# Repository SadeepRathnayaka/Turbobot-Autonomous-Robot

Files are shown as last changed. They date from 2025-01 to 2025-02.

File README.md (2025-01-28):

# Turbobot-Autonomous-Robot

This repository showcases a four-wheel differential drive robot designed and built from scratch. It includes the 3D model design, ROS2 framework integration, localization using EKF, firmware implementation, and hardware bringup. Below are the key aspects of the project:

https://github.com/user-attachments/assets/a37dd53c-2390-4a10-aca8-deebb67d79c1

---

## Table of Contents

1. [3D Model Design](#3d-model-design)
2. [ROS2 Framework Configuration](#ros2-framework-configuration)
3. [ROS2 Localization with EKF](#ros2-localization-with-ekf)
4. [Turbobot Firmware Package](#turbobot-firmware-package)
5. [Turbobot Bringup Package](#turbobot-bringup-package)
6. [TODO](#todo)
7. [Contributing](#contributing)

---

## 3D Model Design

The robot chassis and components were designed in SolidWorks with a focus on robustness and simplicity. Key design features include:

- **Chassis**: Compact and durable, optimized for differential drive control.
- **Motors and Wheels**: Equipped with four 12V DC motors with encoders for precise movement and control.
- **Sensors**: Design accommodates IMU and encoders for accurate localization.

https://github.com/user-attachments/assets/6d96dd51-13d0-4719-9e16-4e17023ca4d6

---

## ROS2 Framework Configuration

The robot is integrated with the ROS2 framework to enable advanced robotic functionalities. The configuration is divided into:

### 1. Turbobot Description Package
- **URDF File**: Created a URDF file from the Solidworks to accurately describe its physical structure.
- **RViz Visualization**: Used RViz2 for real-time visualization of the robot model and its movements.

### 2. Turbobot Controller Package
- **Differential Drive Controller**: Configured the ROS2 control package to manage differential drive mechanics and handle wheel commands.
- **Joint State Publishing**: Ensures real-time feedback of wheel states for visualization and control.

https://github.com/user-attachments/assets/6af6fd65-e95c-474f-9c42-16ca92db2a46

https://github.com/user-attachments/assets/eaf015e2-bc32-4cbf-b950-43cc5cfae7bc

---

## ROS2 Localization with EKF

Localization is implemented using the Extended Kalman Filter (EKF) through the `robot_localization` package. This setup fuses sensor data to provide robust state estimation:

- **Sensor Fusion**: Combines data from wheel encoders and an IMU sensor.
- **EKF Implementation**: Filters noisy sensor data for accurate pose and velocity estimation.

---

## Turbobot Firmware Package

The firmware developed for the robot provides seamless communication between hardware and software:

- **Serial Communication**: Reads commands from ROS2 control via serial interface.
- **Encoder Feedback**: Sends wheel encoder data back to ROS2 control for real-time updates.

https://github.com/user-attachments/assets/950cfb9a-0e33-45bd-b91e-5be3077a2346

https://github.com/user-attachments/assets/f371da3b-ce15-4cfa-9a51-53758e793328

---

## Turbobot Bringup Package

The bringup package initializes and visualizes the robot’s hardware or simulation:

- **Hardware Setup**: Launch file to start the physical robot.
- **Simulated Setup**: RViz2 integration to visualize and test the robot in a simulated environment.

https://github.com/user-attachments/assets/525a8be4-f4b9-4b29-8b2c-a98935a81687

---

## TODO

Future improvements and features:

1. Add a LiDAR sensor for environment scanning.
2. Integrate `nav2` and `slam_toolbox` for autonomous navigation and SLAM.

---

## Contributing

Contributions are welcome! Feel free to submit issues or pull requests for improvements and additional features.

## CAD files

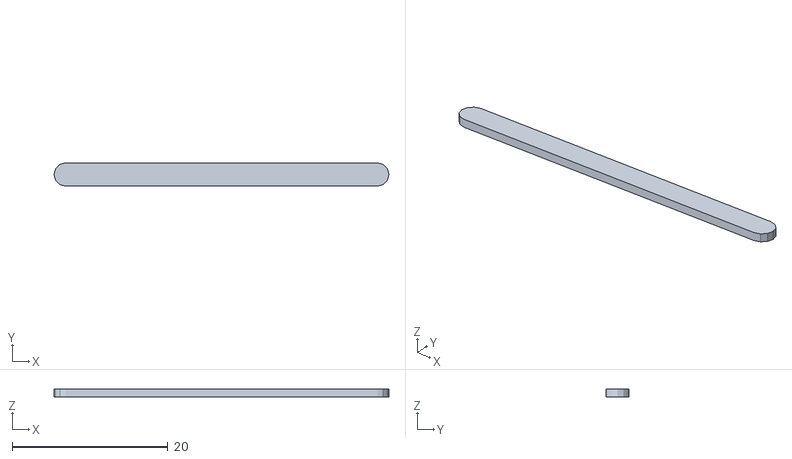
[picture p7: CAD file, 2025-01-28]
CAD Models/Part9_White.STL
43.0 x 3.00 x 1.00

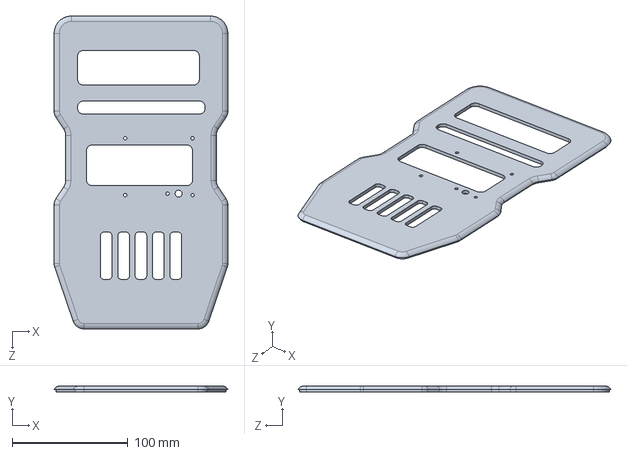
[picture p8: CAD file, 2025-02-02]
CAD Models/Solidworks Parts/Part2.SLDPRT
150.0 x 5.00 x 270.0 mm

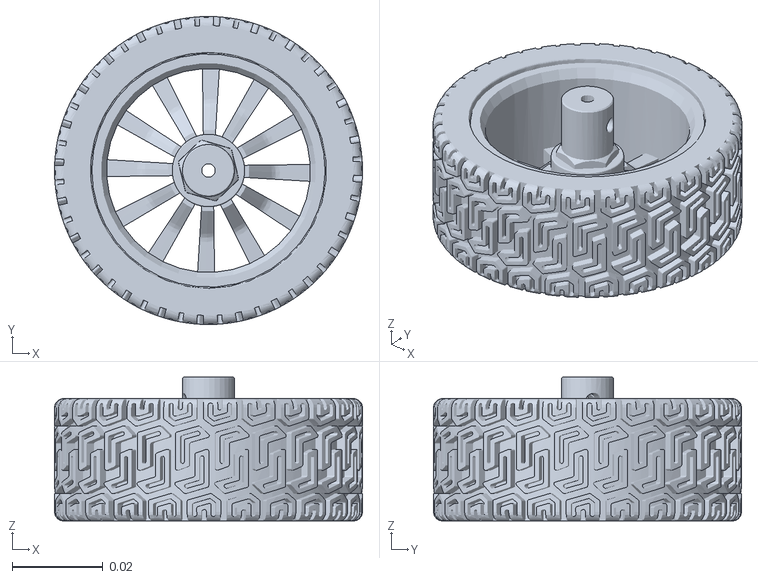
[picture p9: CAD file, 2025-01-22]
turbobot_description/meshes/right_front_wheel_link.STL
0.068 x 0.068 x 0.0318

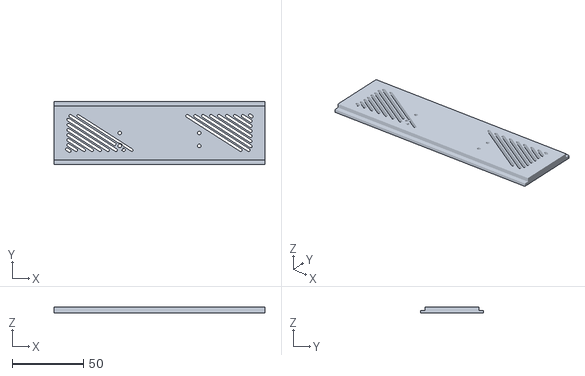
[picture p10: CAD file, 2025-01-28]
CAD Models/Part12.STL
148.0 x 44.0 x 4.50

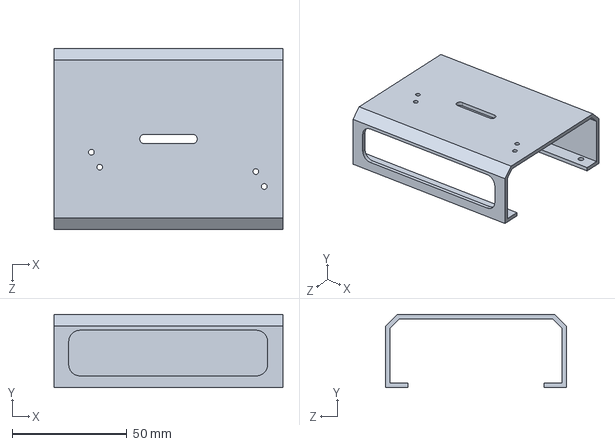
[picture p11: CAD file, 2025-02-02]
CAD Models/Solidworks Parts/Part3.SLDPRT
100.0 x 32.0 x 79.2 mm

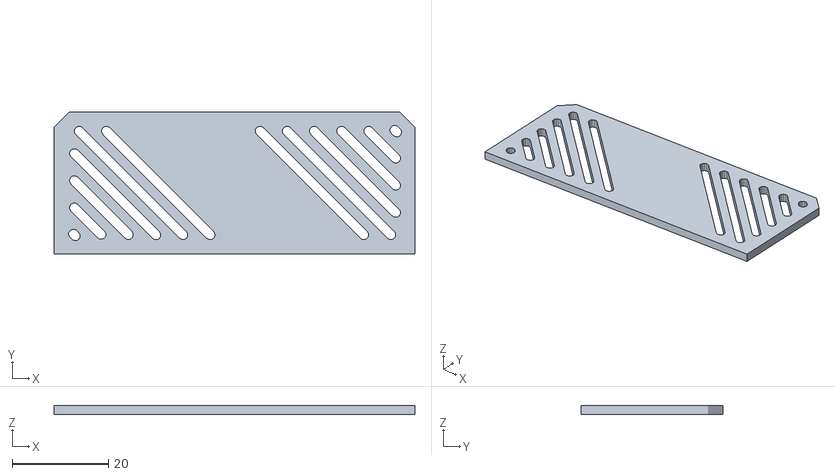
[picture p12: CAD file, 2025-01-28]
CAD Models/Part7.STL
75.2 x 29.6 x 1.90

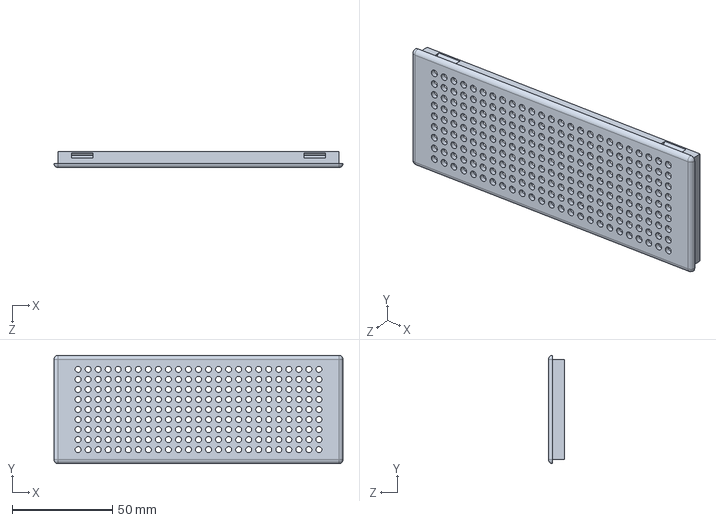
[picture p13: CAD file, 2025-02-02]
CAD Models/Solidworks Parts/Battery_Enclosure_Cover.SLDPRT
144.0 x 54.0 x 8.00 mm

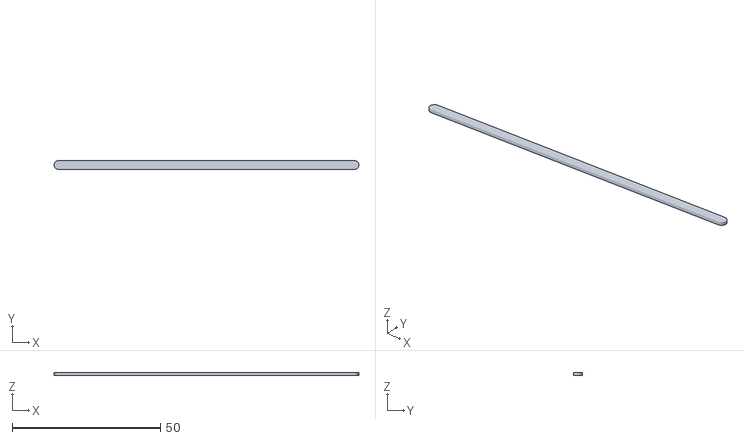
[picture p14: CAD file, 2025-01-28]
CAD Models/Part11_White.STL
103.0 x 3.00 x 1.00

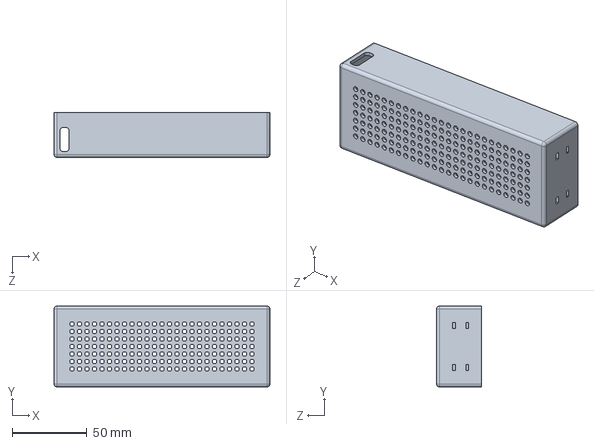
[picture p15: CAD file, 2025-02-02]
CAD Models/Solidworks Parts/Battery_Enclosure_Base.SLDPRT
144.0 x 54.0 x 30.0 mm

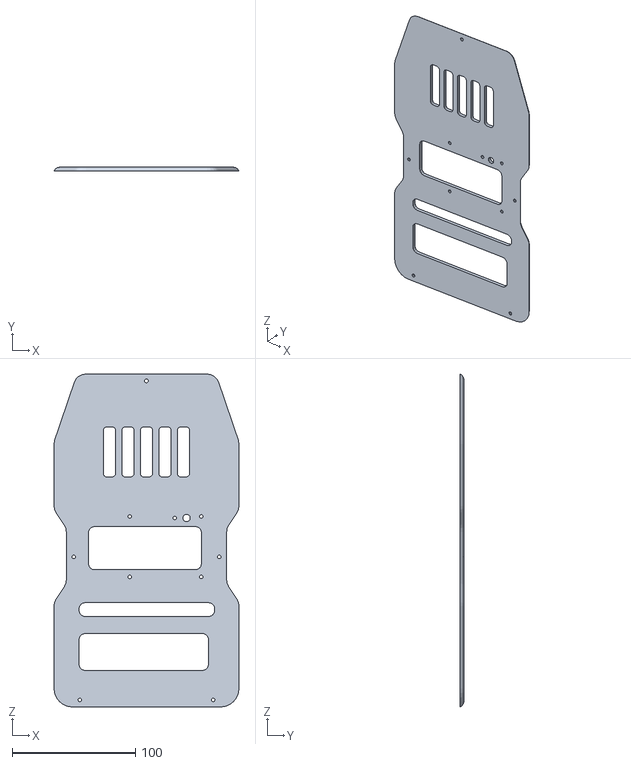
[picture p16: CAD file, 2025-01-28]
CAD Models/Part2_White.STL
150.0 x 3.00 x 270.0

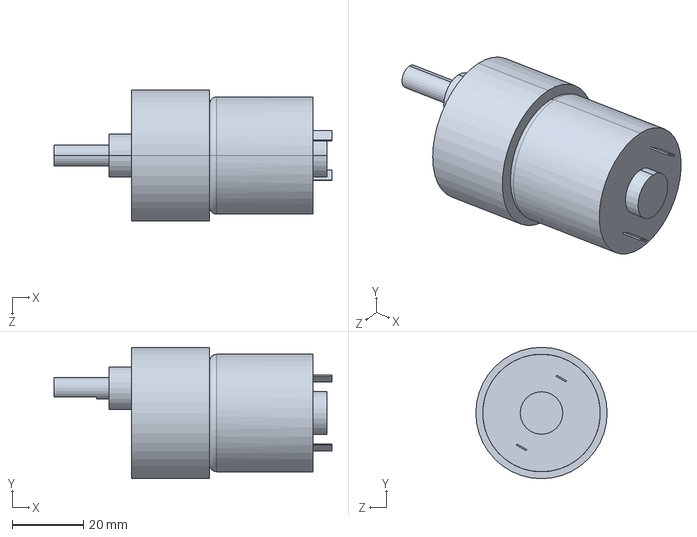
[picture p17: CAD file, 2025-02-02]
CAD Models/Solidworks Parts/DC Gearbox Motor SGD37.step.SLDPRT
78.3 x 37.0 x 37.0 mm

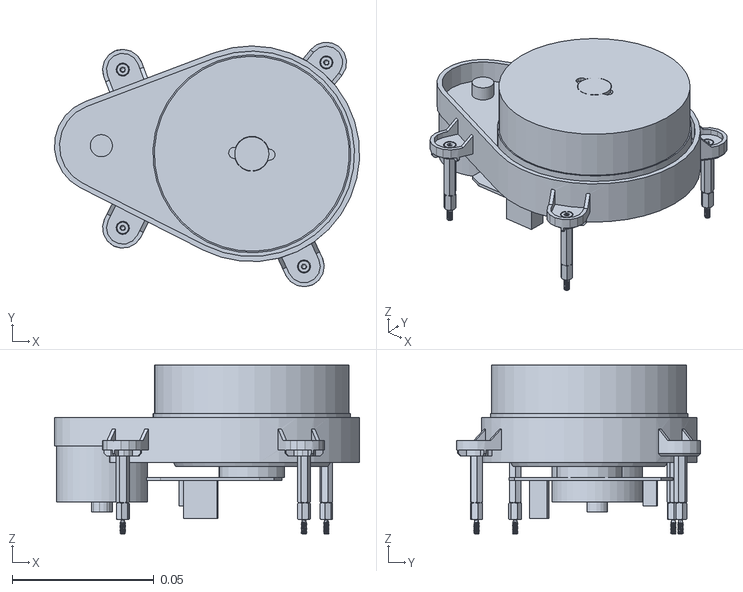
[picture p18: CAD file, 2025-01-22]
turbobot_description/meshes/lidar_link.STL
0.107 x 0.0861 x 0.0595

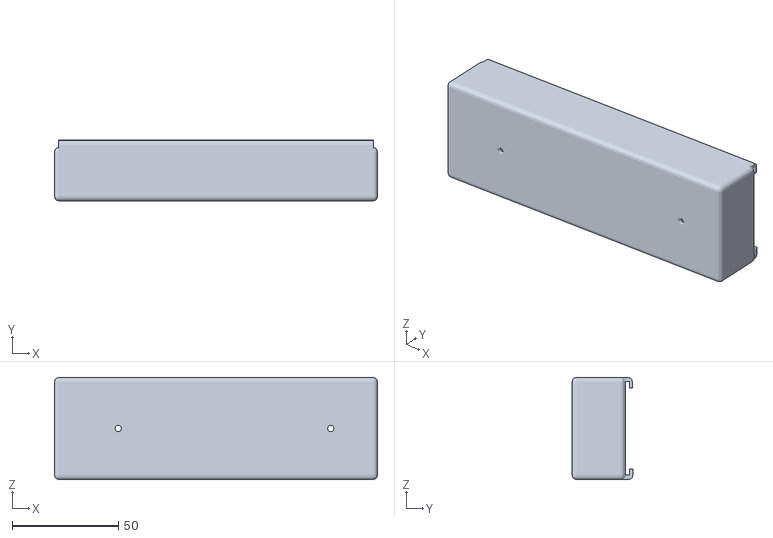
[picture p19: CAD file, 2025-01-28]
CAD Models/Part5.STL
152.0 x 28.5 x 48.0

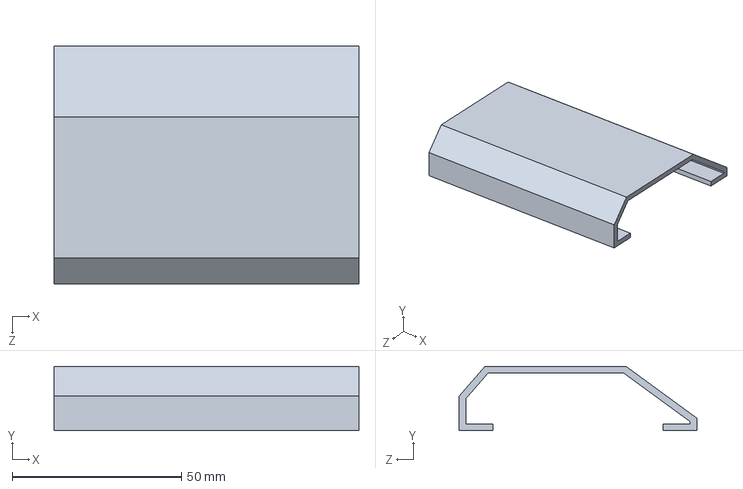
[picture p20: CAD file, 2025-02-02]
CAD Models/Solidworks Parts/Part4.SLDPRT
90.0 x 19.0 x 70.2 mm

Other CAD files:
turbobot_description/meshes/left_front_wheel_link.STL
turbobot_description/meshes/left_back_wheel_link.STL
turbobot_description/meshes/right_back_wheel_link.STL
turbobot_description/meshes/base_link.STL
CAD Models/Part1.STL
CAD Models/Part10_White.STL
CAD Models/Part3.STL
CAD Models/Part4.STL
CAD Models/Part8.STL
CAD Models/Solidworks Parts/MPU6050.SLDPRT
CAD Models/Solidworks Parts/Part1.SLDPRT
CAD Models/Solidworks Parts/Xiaomi Roborock Mi LDS02RR 1st gen LiDAR.SLDPRT
turbobot_description/meshes/IMU_link.STL

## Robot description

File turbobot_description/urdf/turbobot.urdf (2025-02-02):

<?xml version="1.0" encoding="utf-8"?>

<robot name="turbobot" xmlns:xacro="http://ros.org/wiki/xacro">

  <xacro:arg name="is_sim" default="true"/>

  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
  <xacro:include filename="$(find turbobot_description)/urdf/turbobot_gazebo.xacro" />
 
  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
  <xacro:include filename="$(find turbobot_description)/urdf/turbobot_ros2_control.xacro" />


  <link name="base_link">
    <inertial>
      <origin xyz="-0.0106412381739105 0.000371303474620305 0.0284727132515347" rpy="0 0 0" />
      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
        <mass value="0.283253612923317" />
      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
    </inertial>
    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
  </link>

  <link name="left_front_wheel_link">
    <inertial>
      <origin xyz="0.000111982737798819 8.35469957105595E-11 0.00621009180993898" rpy="0 0 0" />
      <mass value="0.0351743502617622" />
      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
    </inertial>
    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
  </link>

  <joint name="left_front_wheel_joint" type="continuous">
    <origin xyz="0.054789 0.094013 0.014388" rpy="-1.5708 -1.5708 0" />
    <parent link="base_link" />
    <child link="left_front_wheel_link" />
    <axis xyz="0 0 1" />
    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
  </joint>

  <link name="left_back_wheel_link">
    <inertial>
      <origin xyz="0.000111984234280757 7.10155073635477E-10 0.00621009181067783" rpy="0 0 0" />
      <mass value="0.0351743510827554" />
      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
    </inertial>
    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
  </link>

  <joint name="left_back_wheel_joint" type="continuous">
    <origin xyz="-0.082396 0.094013 0.014388" rpy="-1.5708 -1.5708 0" />
    <parent link="base_link" />
    <child link="left_back_wheel_link" />
    <axis xyz="0 0 1" />
    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
  </joint>

  <link name="right_front_wheel_link">
    <inertial>
      <origin xyz="-2.96807439736924E-11 -9.20698883413382E-05 -0.00621009190374883" rpy="0 0 0" />
      <mass value="0.0351743518709708" />
      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
    </inertial>
    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
  </link>

  <joint name="right_front_wheel_joint" type="continuous">
    <origin xyz="0.054789 -0.094013 0.014388" rpy="-1.5708 0 0" />
    <parent link="base_link" />
    <child link="right_front_wheel_link" />
    <axis xyz="0 0 1" />
    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
  </joint>

  <link name="right_back_wheel_link">
    <inertial>
      <origin xyz="-8.30065682855263E-10 -0.000111983818113622 -0.0062100919465217" rpy="0 0 0" />
      <mass value="0.0351743514571784" />
      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
    </inertial>
    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
  </link>

  <joint name="right_back_wheel_joint" type="continuous">
    <origin xyz="-0.082396 -0.094013 0.014388" rpy="-1.5708 0 0" />
    <parent link="base_link" />
    <child link="right_back_wheel_link" />
    <axis xyz="0 0 1" />
    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
  </joint>
  
  <link name="lidar_link">
    <inertial>
      <origin xyz="-0.0071639 0.00032796 -0.021434" rpy="0 0 0" />
      <mass value="0.16924" />
      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
    </inertial>
    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
  </link>

  <joint name="lidar_joint" type="fixed">
    <origin xyz="-0.042663 -0.0027565 0.1345" rpy="0 0 0" />
    <parent link="base_link" />
    <child link="lidar_link" />
    <axis xyz="0 0 0" />
  </joint>

  <link name="lidar_tf_link"/>
  <joint name="lidar_tf_joint" type="fixed">
    <parent link="lidar_link"/>
    <child link="lidar_tf_link"/>
    <origin xyz="0 0 0" rpy="3.14 0 0"/>
  </joint>

  <link name="IMU_link">
    <inertial>
      <origin xyz="0.00033795 0.0002439 -0.0013042" rpy="0 0 0" />
      <mass value="0.00035125" />
      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
    </inertial>
    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
  </link>
  
  <joint name="IMU_joint" type="fixed">
    <origin xyz="0.022697 -0.00036685 0.082" rpy="0 0 0.0078865" />
    <parent link="base_link" />
    <child link="IMU_link" />
    <axis xyz="0 1 0" />
  </joint>
  
</robot>

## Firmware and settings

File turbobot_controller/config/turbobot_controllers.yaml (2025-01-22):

controller_manager:
  ros__parameters:
    update_rate: 100 # Hz
    # use_sim_time: true

    turbobot_controller:
      type: diff_drive_controller/DiffDriveController

    joint_state_broadcaster:
      type: joint_state_broadcaster/JointStateBroadcaster


turbobot_controller:
  ros__parameters:
    type        : diff_drive_controller/DiffDriveController
    use_stamped_vel: true
    left_wheel_names  : ["left_front_wheel_joint", "left_back_wheel_joint" ]
    right_wheel_names : ["right_front_wheel_joint", "right_back_wheel_joint" ]

    # wheels_per_side (int)
    # Number of wheels on each side of the robot.
    # This is important to take the wheels slip into account when multiple wheels on each side are present. 
    # If there are more wheels then control signals for each side, you should enter number for control signals. 
    # For example, Husky has two wheels on each side, but they use one control signal, in this case ‘1’ is the correct value of the parameter.

    # Default: 0
    wheels_per_side: 1

    publish_rate: 50.0               # default: 50
    pose_covariance_diagonal : [0.001, 0.001, 1.0e-3, 1.0e-3, 1.0e-3, 0.01]
    twist_covariance_diagonal: [0.001, 0.001, 1.0e-3, 1.0e-3, 1.0e-3, 0.01]

    wheel_separation : 0.188
    wheel_radius : 0.033

    wheel_separation_multiplier: 1.0
    left_wheel_radius_multiplier: 1.0
    right_wheel_radius_multiplier: 1.0

    # Velocity commands timeout [s], default 0.5
    cmd_vel_timeout: 0.5

    # Base frame_id
    base_frame_id: base_link #default: base_link

    # Publish limited velocity
    publish_limited_velocity: true

    # Publish wheel data
    publish_wheel_data: true

    # Publish to TF directly or not
    enable_odom_tf: true

    # Velocity and acceleration limits
    # Whenever a min_* is unspecified, default to -max_*
    linear:
      x:
        has_velocity_limits    : true
        max_velocity           : 0.5  # m/s
        min_velocity           : -0.5 # m/s
        has_acceleration_limits: true
        max_acceleration       : 0.5  # m/s^2
        min_acceleration       : -0.5 # m/s^2
        has_jerk_limits        : false
        max_jerk               : 5.0  # m/s^3
    angular:
      z:
        has_velocity_limits    : true
        max_velocity           : 1.7  # rad/s
        has_acceleration_limits: true
        max_acceleration       : 1.5  # rad/s^2
        has_jerk_limits        : false
        max_jerk               : 2.5  # rad/s^3

# joint_state_broadcaster:
#   ros_parameters:
#     type: joint_state_broadcaster/JointStateBroadcaster
#     publish_rate: 50.0  # Adjust to your desired frequency (in Hz)

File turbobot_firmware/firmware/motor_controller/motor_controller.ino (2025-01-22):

#include <PID_v1.h>
#include <EnableInterrupt.h>
#include <math.h>

// Left Motors Pins (Front and Back)
#define LEFT_MOTOR_IN1 16  
#define LEFT_MOTOR_IN2 17 
#define LEFT_MOTOR_EN  3

#define LEFT_ENCODER_A 12
#define LEFT_ENCODER_B 11

#define LEFT_BACK_ENCODER_A 7
#define LEFT_BACK_ENCODER_B 6

// Right Motors Pins (Front and Back)
#define RIGHT_MOTOR_IN1 15   
#define RIGHT_MOTOR_IN2 14   
#define RIGHT_MOTOR_EN  10

#define RIGHT_ENCODER_A 5
#define RIGHT_ENCODER_B 4

#define RIGHT_BACK_ENCODER_A 9
#define RIGHT_BACK_ENCODER_B 8

// Pulses per Revolution
#define PPR_LEFT 2033
#define PPR_RIGHT 2060

#define INTERVAL 100
#define DELTA_LEFT 10.0
#define DELTA_RIGHT 10.0

volatile long leftPulses = 0, rightPulses = 0 ;
String leftDirection = "p", rightDirection = "p";

volatile long leftBackPulses = 0, rightBackPulses = 0 ;
String leftBackDirection = "p", rightBackDirection = "p";

bool is_left_motor   = true, is_right_motor   = true;
bool is_left_cmd     = true, is_right_cmd     = true ;
bool is_left_forward = true, is_right_forward = true;

char value[] = "00.00";
uint8_t value_idx = 0;
bool is_cmd_complete = false;

static unsigned long lastTime = 0;
float leftTheta  = (2.0 * PI) / PPR_LEFT;
float rightTheta = (2.0 * PI) / PPR_RIGHT;

int led_on = 1;

// PID Variables
double left_wheel_cmd_vel  = 0.0, right_wheel_cmd_vel  = 0.0 ;
double left_wheel_meas_vel = 0.0, right_wheel_meas_vel = 0.0;
double left_wheel_cmd      = 0.0, right_wheel_cmd      = 0.0;

double left_meas_vel_prev  = 0.0; 
double right_meas_vel_prev = 0.0 ;

double left_back_wheel_meas_vel = 0.0, right_back_wheel_meas_vel = 0.0;

// PID Parameters for Forward
double Kp_l_forward = 12.8, Ki_l_forward = 9.5, Kd_l_forward = 0.1;
double Kp_r_forward = 12.8, Ki_r_forward = 9.5, Kd_r_forward = 0.1;

double Kp_l_backward = 8.0, Ki_l_backward = 0.1, Kd_l_backward = 1.0;
double Kp_r_backward = 8.0,  Ki_r_backward = 0.1, Kd_r_backward = 1.0;
//
//double Kp_l_backward = 11.5, Ki_l_backward = 0.0, Kd_l_backward = 0.0;
//double Kp_r_backward = 11.5,  Ki_r_backward = 0.0, Kd_r_backward = 0.0;

PID leftMotor(&left_wheel_meas_vel, &left_wheel_cmd, &left_wheel_cmd_vel, Kp_l_forward, Ki_l_forward, Kd_l_forward, DIRECT);
PID rightMotor(&right_wheel_meas_vel, &right_wheel_cmd, &right_wheel_cmd_vel, Kp_r_forward, Ki_r_forward, Kd_r_forward, DIRECT);


void setup() {
  pinMode(LEFT_MOTOR_IN1, OUTPUT);
  pinMode(LEFT_MOTOR_IN2, OUTPUT);
  pinMode(LEFT_MOTOR_EN, OUTPUT);

  pinMode(RIGHT_MOTOR_IN1, OUTPUT);
  pinMode(RIGHT_MOTOR_IN2, OUTPUT);
  pinMode(RIGHT_MOTOR_EN, OUTPUT);

  pinMode(LEFT_ENCODER_A, INPUT);
  pinMode(LEFT_ENCODER_B, INPUT);

  pinMode(LEFT_BACK_ENCODER_A, INPUT);
  pinMode(LEFT_BACK_ENCODER_B, INPUT);

  pinMode(RIGHT_BACK_ENCODER_A, INPUT);
  pinMode(RIGHT_BACK_ENCODER_B, INPUT);

  digitalWrite(LEFT_MOTOR_IN1, HIGH);
  digitalWrite(LEFT_MOTOR_IN2, LOW);
  digitalWrite(RIGHT_MOTOR_IN1, HIGH);
  digitalWrite(RIGHT_MOTOR_IN2, LOW);

  leftMotor.SetMode(AUTOMATIC);
  rightMotor.SetMode(AUTOMATIC);

  Serial.begin(115200);

  enableInterrupt(LEFT_ENCODER_A, leftEncoderISR, CHANGE);
  enableInterrupt(RIGHT_ENCODER_A, rightEncoderISR, CHANGE);

  enableInterrupt(LEFT_BACK_ENCODER_A, leftBackEncoderISR, CHANGE);
  enableInterrupt(RIGHT_BACK_ENCODER_A, rightBackEncoderISR, CHANGE);

  pinMode(LED_BUILTIN, OUTPUT);

}

// lp08.51,rn08.51,
void loop() {
  if (Serial.available()) {
    char chr = Serial.read();

    if (chr == 'l')
    {
      is_left_motor = true;
      is_right_motor = false;
      is_cmd_complete = false;
      value_idx = 0;
    }
    else if (chr == 'r') 
    {
      is_left_motor = false;
      is_right_motor = true;
      is_cmd_complete = false;
      value_idx = 0;
    } 
    else if (chr == 'p') 
    {
      if (is_left_motor) 
      {
        digitalWrite(LEFT_MOTOR_IN1, HIGH);
        digitalWrite(LEFT_MOTOR_IN2, LOW);
        is_left_forward = true;
        updatePIDParams(leftMotor, Kp_l_forward, Ki_l_forward, Kd_l_forward);
//        resetPIDStates(leftMotor);
      } 
      else if (is_right_motor) 
      {
        digitalWrite(RIGHT_MOTOR_IN1, HIGH);
        digitalWrite(RIGHT_MOTOR_IN2, LOW);
        is_right_forward = true;
         updatePIDParams(rightMotor, Kp_r_forward, Ki_r_forward, Kd_r_forward);
//         resetPIDStates(rightMotor);
      } 
    } 
    else if (chr == 'n') {
      if (is_left_motor) 
      {
        digitalWrite(LEFT_MOTOR_IN1, LOW);
        digitalWrite(LEFT_MOTOR_IN2, HIGH);
        is_left_forward = false;
        updatePIDParams(leftMotor, Kp_l_backward, Ki_l_backward, Kd_l_backward);
//        resetPIDStates(leftMotor);
      } 
      else if (is_right_motor) 
      {
        digitalWrite(RIGHT_MOTOR_IN1, LOW);
        digitalWrite(RIGHT_MOTOR_IN2, HIGH);
        is_right_forward = false;
        updatePIDParams(rightMotor, Kp_r_backward, Ki_r_backward, Kd_r_backward);
//        resetPIDStates(rightMotor);
      } 
    } 
    else if (chr == ',') {
      double parsedValue = atof(value);
      if (is_left_motor) left_wheel_cmd_vel = parsedValue;
      else if (is_right_motor) {
        right_wheel_cmd_vel = parsedValue;
        is_cmd_complete = true;
      }
      value_idx = 0;
      value[0] = '0';
      value[1] = '0';
      value[2] = '.';
      value[3] = '0';
      value[4] = '0';
      value[5] = '\0';
      
    }
    else
    {
      if (value_idx < 5)
      {
      value[value_idx] = chr;
      value_idx++;
      }
    }
  }

  unsigned long currentTime = millis();
  if (currentTime - lastTime >= INTERVAL) {
    left_wheel_meas_vel       = (leftPulses * leftTheta) / (currentTime - lastTime) * 1000;
    left_back_wheel_meas_vel  = (leftBackPulses * leftTheta) / (currentTime - lastTime) * 1000;
    right_wheel_meas_vel      = (rightPulses * rightTheta) / (currentTime - lastTime) * 1000;
    right_back_wheel_meas_vel = (rightBackPulses * rightTheta) / (currentTime - lastTime) * 1000;

    double delta_left  = fabs(left_wheel_meas_vel  - left_meas_vel_prev)  ;
    double delta_right = fabs(right_wheel_meas_vel - right_meas_vel_prev) ;

    if (delta_left > DELTA_LEFT)
    {
      left_wheel_meas_vel = left_meas_vel_prev ;
    }
    if (delta_right > DELTA_RIGHT)
    {
      right_wheel_meas_vel = right_meas_vel_prev ;
    }

    leftMotor.Compute();
    rightMotor.Compute();

    if (left_wheel_cmd_vel == 0 )
    {
      left_wheel_cmd = 0 ;
    } 
   
    if (right_wheel_cmd_vel == 0) 
    {
      right_wheel_cmd = 0 ;
    }

//   Serial.print("left front wheel measured vel : ");
//   Serial.println(left_wheel_meas_vel);
//   Serial.print("left back wheel measured vel : ");
//   Serial.println(left_back_wheel_meas_vel);
//   Serial.print("right front wheel measured vel : ");
//   Serial.println(right_wheel_meas_vel);
//   Serial.print("right back wheel measured vel : ");
//   Serial.println(right_back_wheel_meas_vel);

    analogWrite(LEFT_MOTOR_EN, left_wheel_cmd);
    analogWrite(RIGHT_MOTOR_EN, right_wheel_cmd);

    leftPulses = rightPulses = 0;
    leftBackPulses = rightBackPulses = 0 ;
    lastTime = currentTime;
    left_meas_vel_prev  = left_wheel_meas_vel ;
    right_meas_vel_prev = right_wheel_meas_vel ;

    digitalWrite(LED_BUILTIN, !led_on);
    led_on = !led_on;

    String velocity_msg = "l" + leftDirection  + componsateZeros(left_wheel_meas_vel)  + "," +
                          "r" + rightDirection + componsateZeros(right_wheel_meas_vel) + "," ;

    // String velocity_msg = "l" + leftDirection  + String(left_wheel_meas_vel)  + "," +
    //                       "r" + rightDirection + String(right_wheel_meas_vel) + "," ;
                          
    Serial.println(velocity_msg);
  }
}



void leftEncoderISR() {
  if (digitalRead(LEFT_ENCODER_A) != digitalRead(LEFT_ENCODER_B)) {
    leftPulses++;
    leftDirection = "p";
  } else {
    leftPulses--;
    leftDirection = "n";
  }
}


void rightEncoderISR() {
  if (digitalRead(RIGHT_ENCODER_A) == digitalRead(RIGHT_ENCODER_B)) {
    rightPulses++;
    rightDirection = "p";
  } else {
    rightPulses--;
    rightDirection = "n";
  }
}

void leftBackEncoderISR() {
  if (digitalRead(LEFT_BACK_ENCODER_A) != digitalRead(LEFT_BACK_ENCODER_B)) {
    leftBackPulses++;
    leftBackDirection = "p";
  } else {
    leftBackPulses--;
    leftBackDirection = "n";
  }
}


void rightBackEncoderISR() {
  if (digitalRead(RIGHT_BACK_ENCODER_A) == digitalRead(RIGHT_BACK_ENCODER_B)) {
    rightBackPulses++;
    rightBackDirection = "p";
  } else {
    rightBackPulses--;
    rightBackDirection = "n";
  }
}

String componsateZeros(float vel) {
  vel = abs(vel);
  if (vel == 0.0) return "00.00";
  String velStr = String(vel, 2);
  while (velStr.length() < 5) velStr = "0" + velStr;
  return velStr;
}


void updatePIDParams(PID& pid, double Kp, double Ki, double Kd) {
    pid.SetTunings(Kp, Ki, Kd);
}


void resetPIDStates(PID& pid) {
    pid.SetMode(MANUAL);    // Disable the PID controller
    pid.SetMode(AUTOMATIC); // Re-enable it, effectively resetting its states
}

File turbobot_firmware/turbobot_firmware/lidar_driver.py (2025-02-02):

#!/usr/bin/env python3


import rclpy
from rclpy.node import Node
from sensor_msgs.msg import LaserScan
import serial
import math
import time

class LidarDataPublisher(Node):
    def __init__(self):
        super().__init__('lidar_data_publisher')
        
        self.DATA_LENGTH = 7  # Data length: angle, speed, distance 1-4, checksum
        self.MAX_DISTANCE = 3.0  # Maximum distance in meters
        self.MIN_DISTANCE = 0.1  # Minimum distance in meters
        self.port = '/dev/ttyUSB0'  # Specify serial port
        self.BAUDRATE = 115200
        self.MAX_DATA_SIZE = 360  # Number of data points (1 degree resolution)
        self.COUNT = 0
        
        self.laser_scan_publisher = self.create_publisher(LaserScan, 'scan', 10)
        self.serial_connection = self.connect_serial(self.port, self.BAUDRATE)
        self.data = {
            'angles': [],
            'distances': []
        }
        
    def connect_serial(self, port: str, baudrate: int):
        try:
            ser = serial.Serial(port, baudrate, timeout=1)
            ser.reset_input_buffer()
            self.get_logger().info(f"Serial connection established at {port}")
            return ser
        except Exception as e:
            self.get_logger().error(f"Failed to connect to serial port: {e}")
            return None

    def publish_scan(self):
        scan = LaserScan()
        scan.header.stamp = self.get_clock().now().to_msg()
        scan.header.frame_id = 'lidar_link'
        scan.angle_min = 0.0
        scan.angle_max = 2 * math.pi
        scan.angle_increment = math.pi / 180.0  # 1 degree in radians
        scan.time_increment = 0.0  # Assuming a stationary scanner
        scan.scan_time = 0.1  # Approximate scan time
        scan.range_min = self.MIN_DISTANCE
        scan.range_max = self.MAX_DISTANCE
        
        ranges = [float('inf')] * self.MAX_DATA_SIZE  # Initialize ranges with 'inf'

        for angle, distance in zip(self.data['angles'], self.data['distances']):
            index = int(angle * 180 / math.pi) % self.MAX_DATA_SIZE  # Map angle to index
            ranges[index] = distance
        
        scan.ranges = ranges
        scan.intensities = []  # No intensity data
        
        self.laser_scan_publisher.publish(scan)
        self.get_logger().info("LaserScan message published")
        
        # Clear data for the next scan
        self.data['angles'].clear()
        self.data['distances'].clear()

    def read_lidar_data(self):
        if not self.serial_connection:
            self.get_logger().error("Serial connection not established")
            return
        
        while rclpy.ok():
            try:
                if self.serial_connection.in_waiting > 0:
                    line = self.serial_connection.readline().decode().strip()
                    sensor_data = line.split('\t')
                    
                    if len(sensor_data) == self.DATA_LENGTH:
                        for i in range(2, 6):  # Process 4 distance readings
                            try:
                                angle = (int(sensor_data[0]) + i - 1) * math.pi / 180.0  # Radians
                                distance = float(sensor_data[i]) / 1000.0  # Convert mm to meters
                                
                                if self.MIN_DISTANCE <= distance <= self.MAX_DISTANCE:
                                    self.data['angles'].append(angle)
                                    self.data['distances'].append(distance)
                                    self.get_logger().info(f"angle : {angle}")
                                    self.get_logger().info(f"distance : {distance}")
                                    self.get_logger().info(f"count : {self.COUNT}")
                                    self.get_logger().info("------------------------")
                                    
                            except ValueError:
                                print("Value error")
                                continue

                        if len(self.data['angles']) >= 350:
                            self.publish_scan()
                            self.COUNT += 1
            except Exception as e:
                self.get_logger().error(f"Error reading LiDAR data: {e}")
            time.sleep(0.001)  # Slight delay to reduce CPU usage

def main(args=None):
    rclpy.init(args=args)
    node = LidarDataPublisher()
    try:
        node.read_lidar_data()
    except KeyboardInterrupt:
        node.get_logger().info("Shutting down node")
    finally:
        rclpy.shutdown()

if __name__ == '__main__':
    main()

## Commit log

2025-01-28 add STL files
    [Part1.STL, Part10_White.STL, Part11_White.STL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]
2025-02-02 Update CAD Models
    [Battery_Enclosure_Base.SLDPRT, Battery_Enclosure_Cover.SLDPRT, DC Gearbox Motor SGD37.step.SLDPRT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]
